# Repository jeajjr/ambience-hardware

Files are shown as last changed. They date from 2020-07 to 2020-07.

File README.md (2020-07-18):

# Ambience hardware

## The project

Project page: [Ambience](https://jeajjr.github.io/ambience/)

## Hardware project

This repository contains the Eagle schematic and board layout of the project.

Software used: Autodesk Eagle 9

The hardware project uses an ESP8266 along with power control circuits to control:
* a 12V RGB LED bar
* two 5V digital outputs, intened to control an Arduino relay board.

## Layout

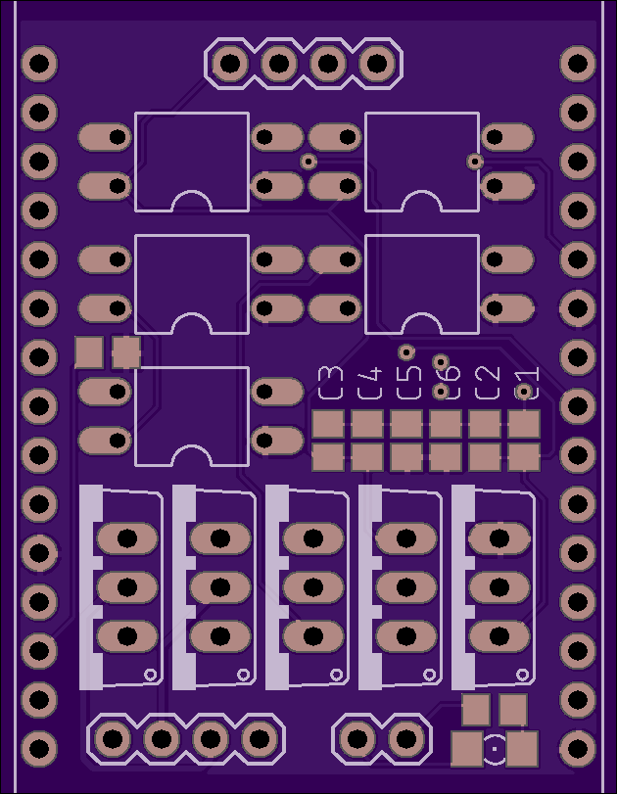
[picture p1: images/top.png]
Top layer

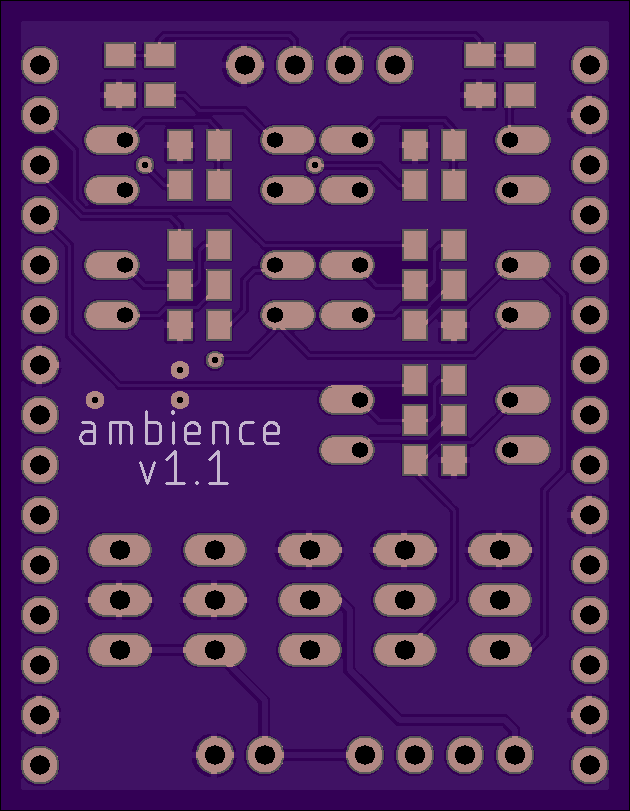
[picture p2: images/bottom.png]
Bottom layer


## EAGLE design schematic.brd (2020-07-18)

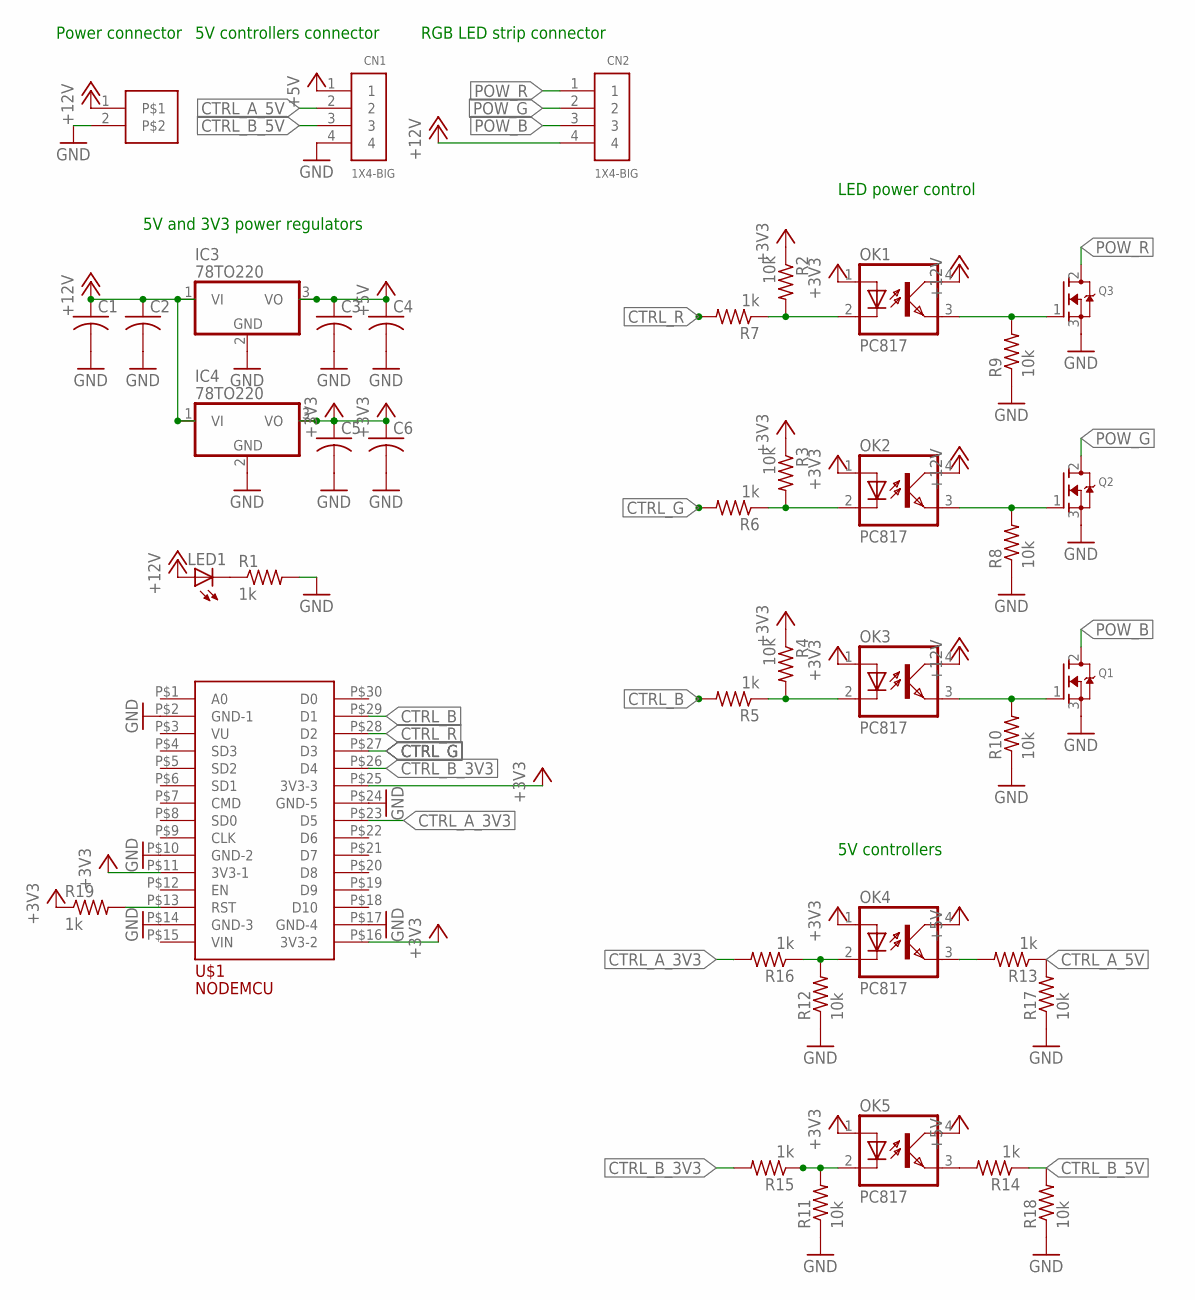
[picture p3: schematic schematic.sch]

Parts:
C1, C2, C3, C4, C5, C6: C-USC0805; C0805
CN1, CN2: 1X4-BIG; 1X04-BIG
IC3, IC4: 78TO220; TO220V
LED1: LEDSMT1206; 1206
OK1, OK2, OK3, OK4, OK5: PC817; DIL04
Q1, Q2, Q3: MOSFET-NGDS_TO220V; TO220V
R1, R19: 1k; M0805
R2, R3, R4, R8, R9, R10, R11, R12, R17, R18: 10k; R0805
R5, R6, R7, R13, R14, R15, R16: 1k; R0805
U$1: ESP8266; ESP8266-NODEMCU
U$2: HEADER-2X1

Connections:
+3V3: C5.1, C6.1, IC4.3 (VO), OK1.1 (A), OK2.1 (A), OK3.1 (A), OK4.1 (A), OK5.1 (A), R2.1, R3.1, R4.1, R19.1, U$1.P$11 (3V3-1), U$1.P$16 (3V3-2), U$1.P$25 (3V3-3)
+5V: C3.1, C4.1, CN1.1, IC3.3 (VO), OK4.4 (COL), OK5.4 (COL)
+12V: C1.1, C2.1, CN2.4, IC3.1 (VI), IC4.1 (VI), LED1.A, OK1.4 (COL), OK2.4 (COL), OK3.4 (COL), U$2.1
CTRL_A_3V3: R16.2, U$1.P$23 (D5)
CTRL_A_5V: CN1.2, R13.1, R17.2
CTRL_B: R5.2, U$1.P$29 (D1)
CTRL_B_3V3: R15.2, U$1.P$26 (D4)
CTRL_B_5V: CN1.3, R14.1, R18.2
CTRL_G: R6.2, U$1.P$27 (D3)
CTRL_R: R7.2, U$1.P$28 (D2)
GND: C1.2, C2.2, C3.2, C4.2, C5.2, C6.2, CN1.4, IC3.2 (GND), IC4.2 (GND), Q1.3 (S), Q2.3 (S), Q3.3 (S), R1.2, R8.1, R9.1, R10.1, R11.1, R12.1, R17.1, R18.1, U$1.P$2 (GND-1), U$1.P$10 (GND-2), U$1.P$14 (GND-3), U$1.P$17 (GND-4), U$1.P$24 (GND-5), U$2.2
unnamed: OK1.2 (C), R2.2, R7.1
unnamed: LED1.C, R1.1
unnamed: OK2.2 (C), R3.2, R6.1
unnamed: OK3.2 (C), R4.2, R5.1
unnamed: OK3.3 (EMIT), Q1.1 (G), R10.2
unnamed: OK2.3 (EMIT), Q2.1 (G), R8.2
unnamed: OK1.3 (EMIT), Q3.1 (G), R9.2
unnamed: R19.2, U$1.P$13 (RST)
unnamed: OK5.3 (EMIT), R14.2
unnamed: OK5.2 (C), R11.2, R15.1
unnamed: OK4.2 (C), R12.2, R16.1
unnamed: OK4.3 (EMIT), R13.2
POW_B: CN2.3, Q1.2 (D)
POW_G: CN2.2, Q2.2 (D)
POW_R: CN2.1, Q3.2 (D)

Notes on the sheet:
Power connector
5V controllers connector
RGB LED strip connector
5V and 3V3 power regulators
LED power control
5V controllers

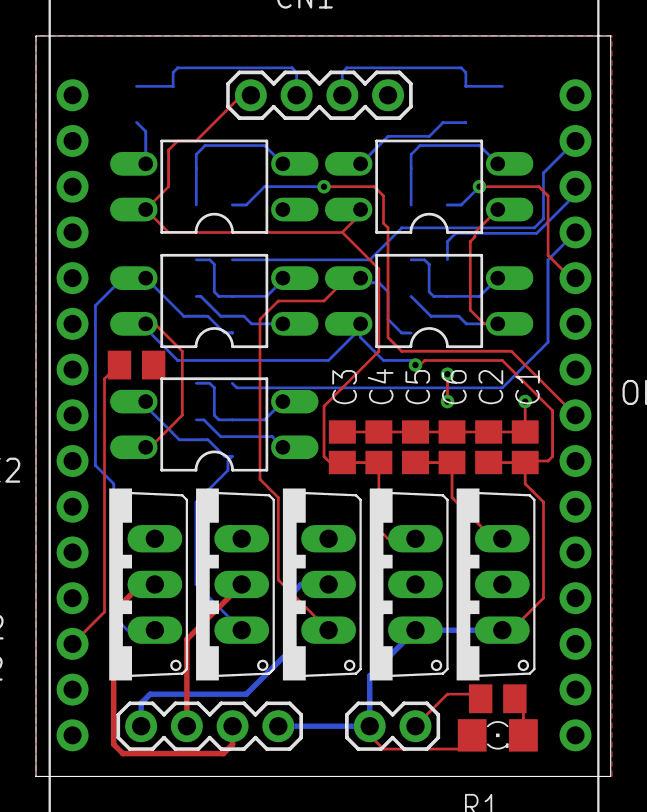
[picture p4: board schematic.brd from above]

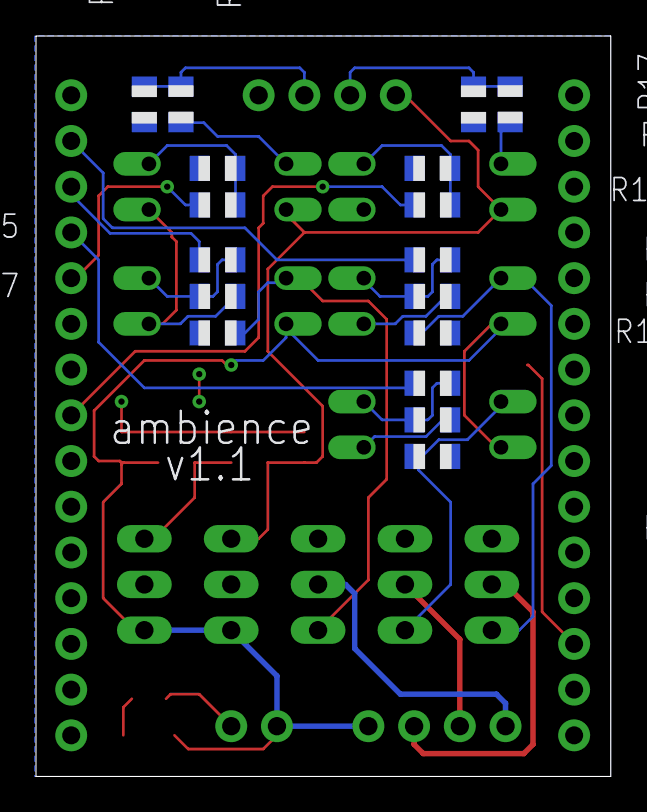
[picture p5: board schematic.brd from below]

Board: 2 copper layers, 31.9 x 41.1 mm, 40 parts (17 on the bottom side), 26 nets.

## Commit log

2017-08-22 Created schematic; Pre-organized components on PCB
    [schematic.brd, schematic.sch]
2017-08-30 Initial board layout
    [schematic.brd, schematic.sch]
2017-08-30 Removed components names from board
    [schematic.brd]
2018-11-15 Inverted polarity of LED control on optocouplers
    [schematic.brd, schematic.sch]
2020-05-24 Updated board; enhanced schematics organization
    [schematic.brd, schematic.sch]
